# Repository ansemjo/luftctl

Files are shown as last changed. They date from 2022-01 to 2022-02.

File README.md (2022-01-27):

# luftctl

Small ESP32-C3 controller board to power two 12V PWM fans from a single USB plug.

## hardware

Schematic and PCB design can be found in [`hardware/`](hardware/). It is a KiCAD 6 project.

The schematic is available as [a PDF](schematic.pdf).

## firmware

The first simple test just loops through {`5V/off`, `5V/on`, `12V/off`, `12V/on`} with every button press.

Download MicroPython from [micropython.org/download/esp32c3-usb/](https://micropython.org/download/esp32c3-usb/) and flash it with:

```
esptool.py --chip esp32c3 --port /dev/ttyACM0 erase_flash
esptool.py --chip esp32c3 --port /dev/ttyACM0 --baud 460800 write_flash -z 0x0 esp32c3-*.bin
```

Then install a virtualenv with `adafruit-ampy` and upload the [`main.py`](main.py):

```
ampy -p /dev/ttyACM0 put main.py
ampy -p /dev/ttyACM0 reset --hard
```

The red LED will blink upon every state change.

## images

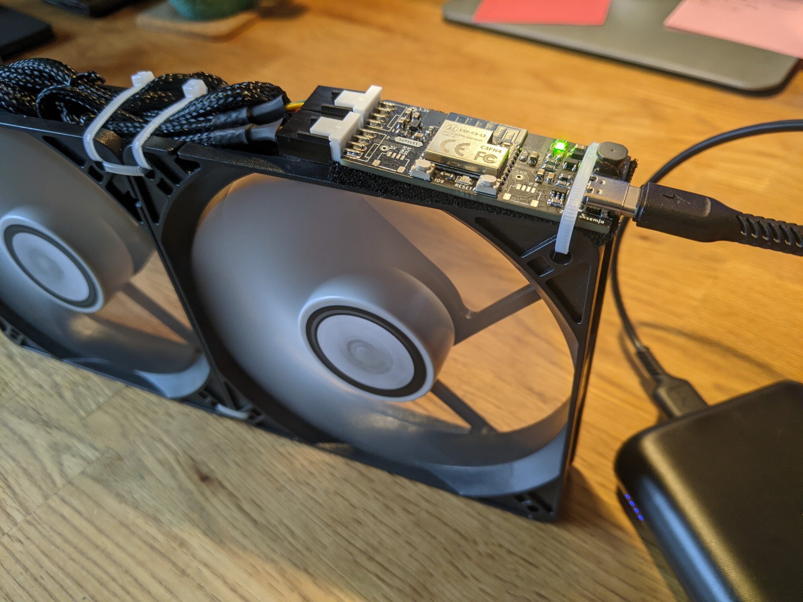
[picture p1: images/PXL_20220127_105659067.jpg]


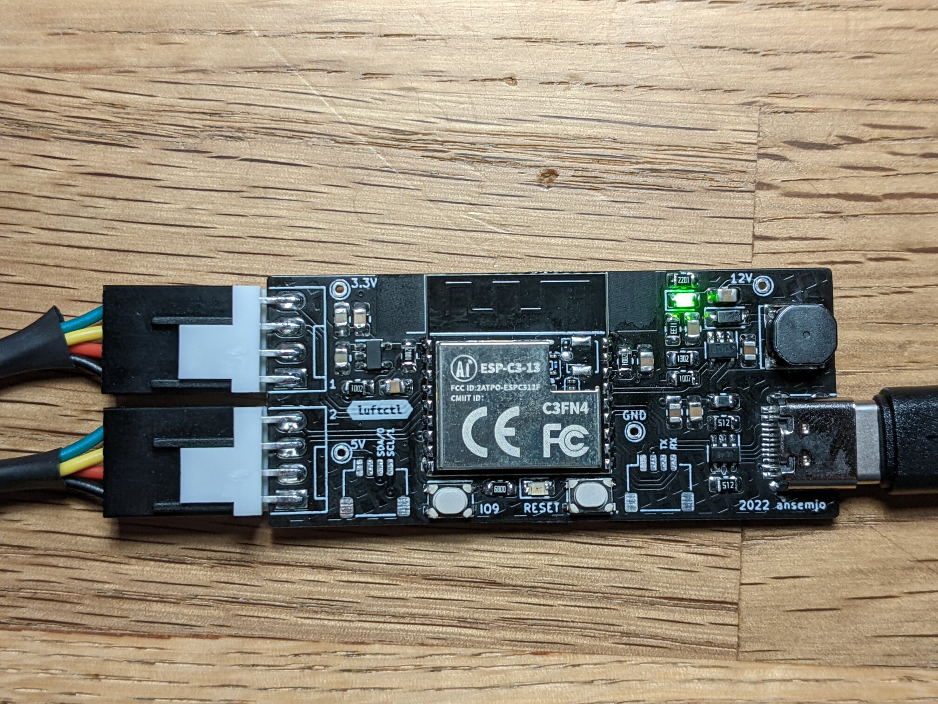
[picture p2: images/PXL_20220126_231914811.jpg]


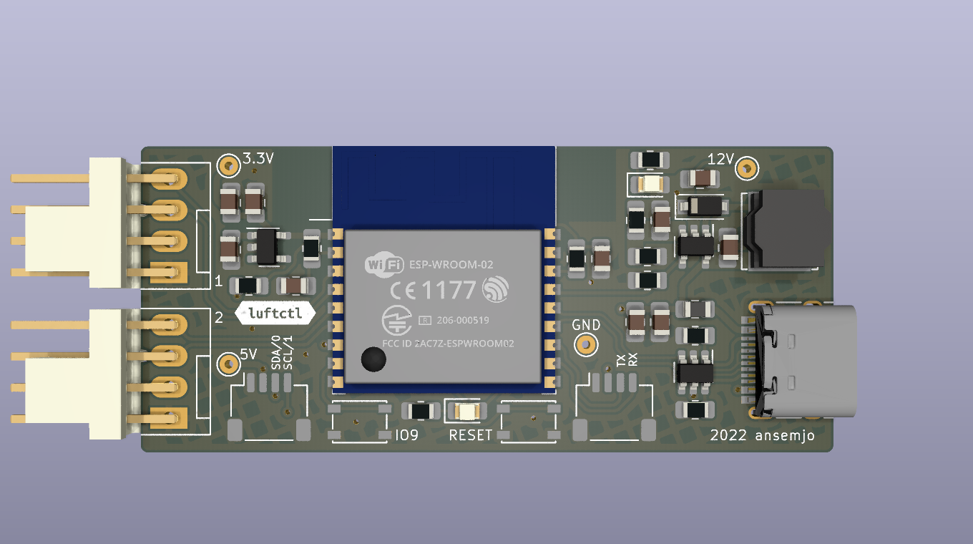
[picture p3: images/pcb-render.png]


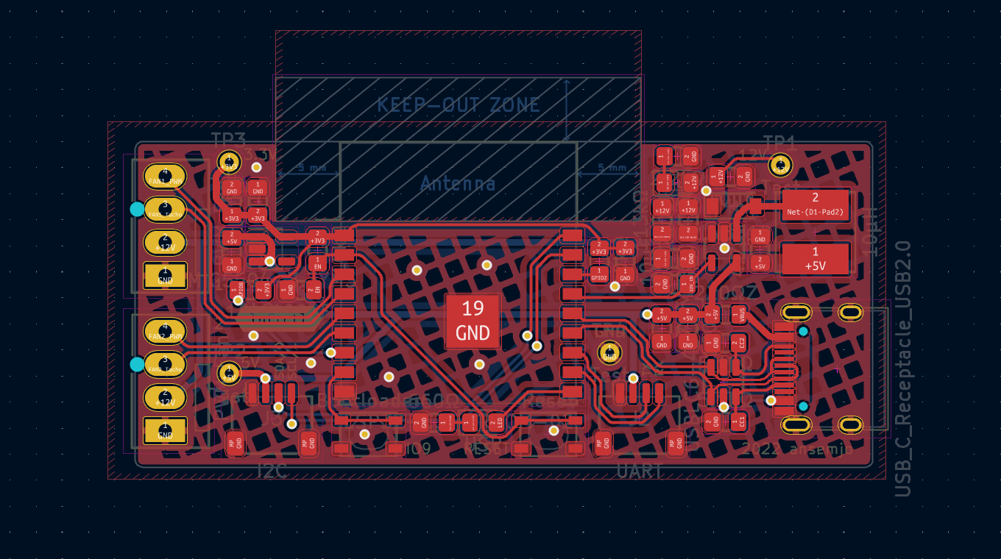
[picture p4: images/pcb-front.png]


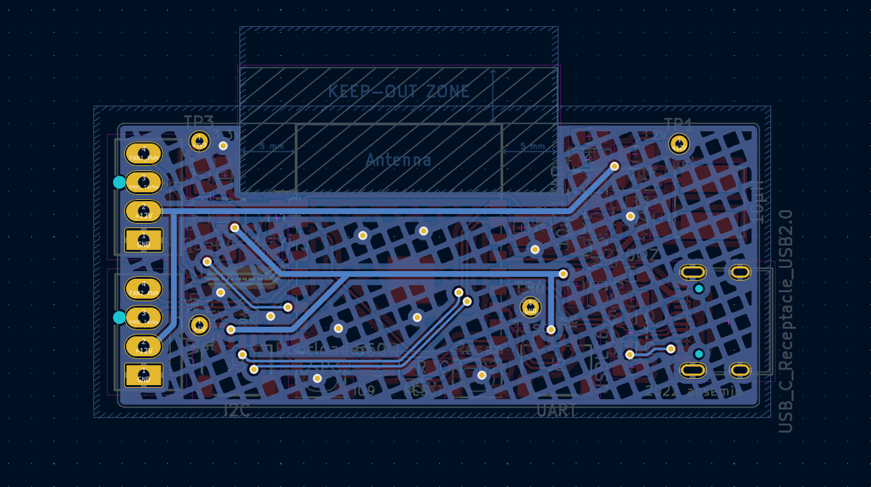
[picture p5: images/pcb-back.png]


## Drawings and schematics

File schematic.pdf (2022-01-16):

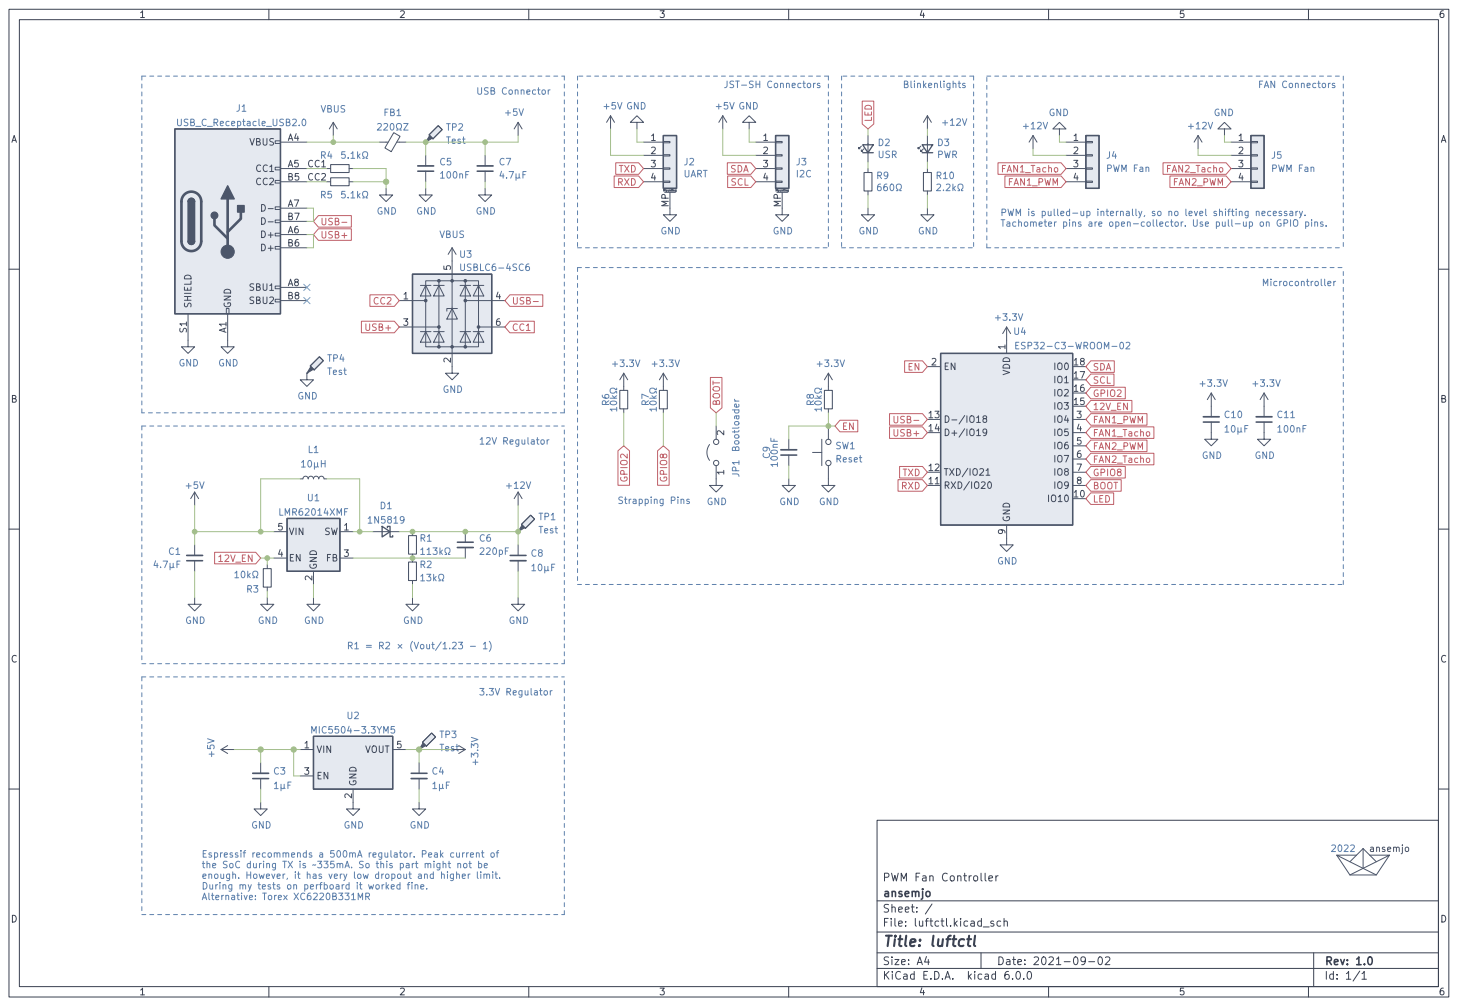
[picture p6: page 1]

Tachometer pins are open-collector. Use pull-up on GPIO pins. USB Connector 12V Regulator

Espressif recommends a 500mA regulator. Peak current of
the SoC during TX is ~335mA. So this part might not be
enough. However, it has very low dropout and higher limit.
During my tests on perfboard it worked fine. Alternative: Torex XC6220B331MR

File: luftctl.kicad_sch Sheet: / ansemjo PWM Fan Controller

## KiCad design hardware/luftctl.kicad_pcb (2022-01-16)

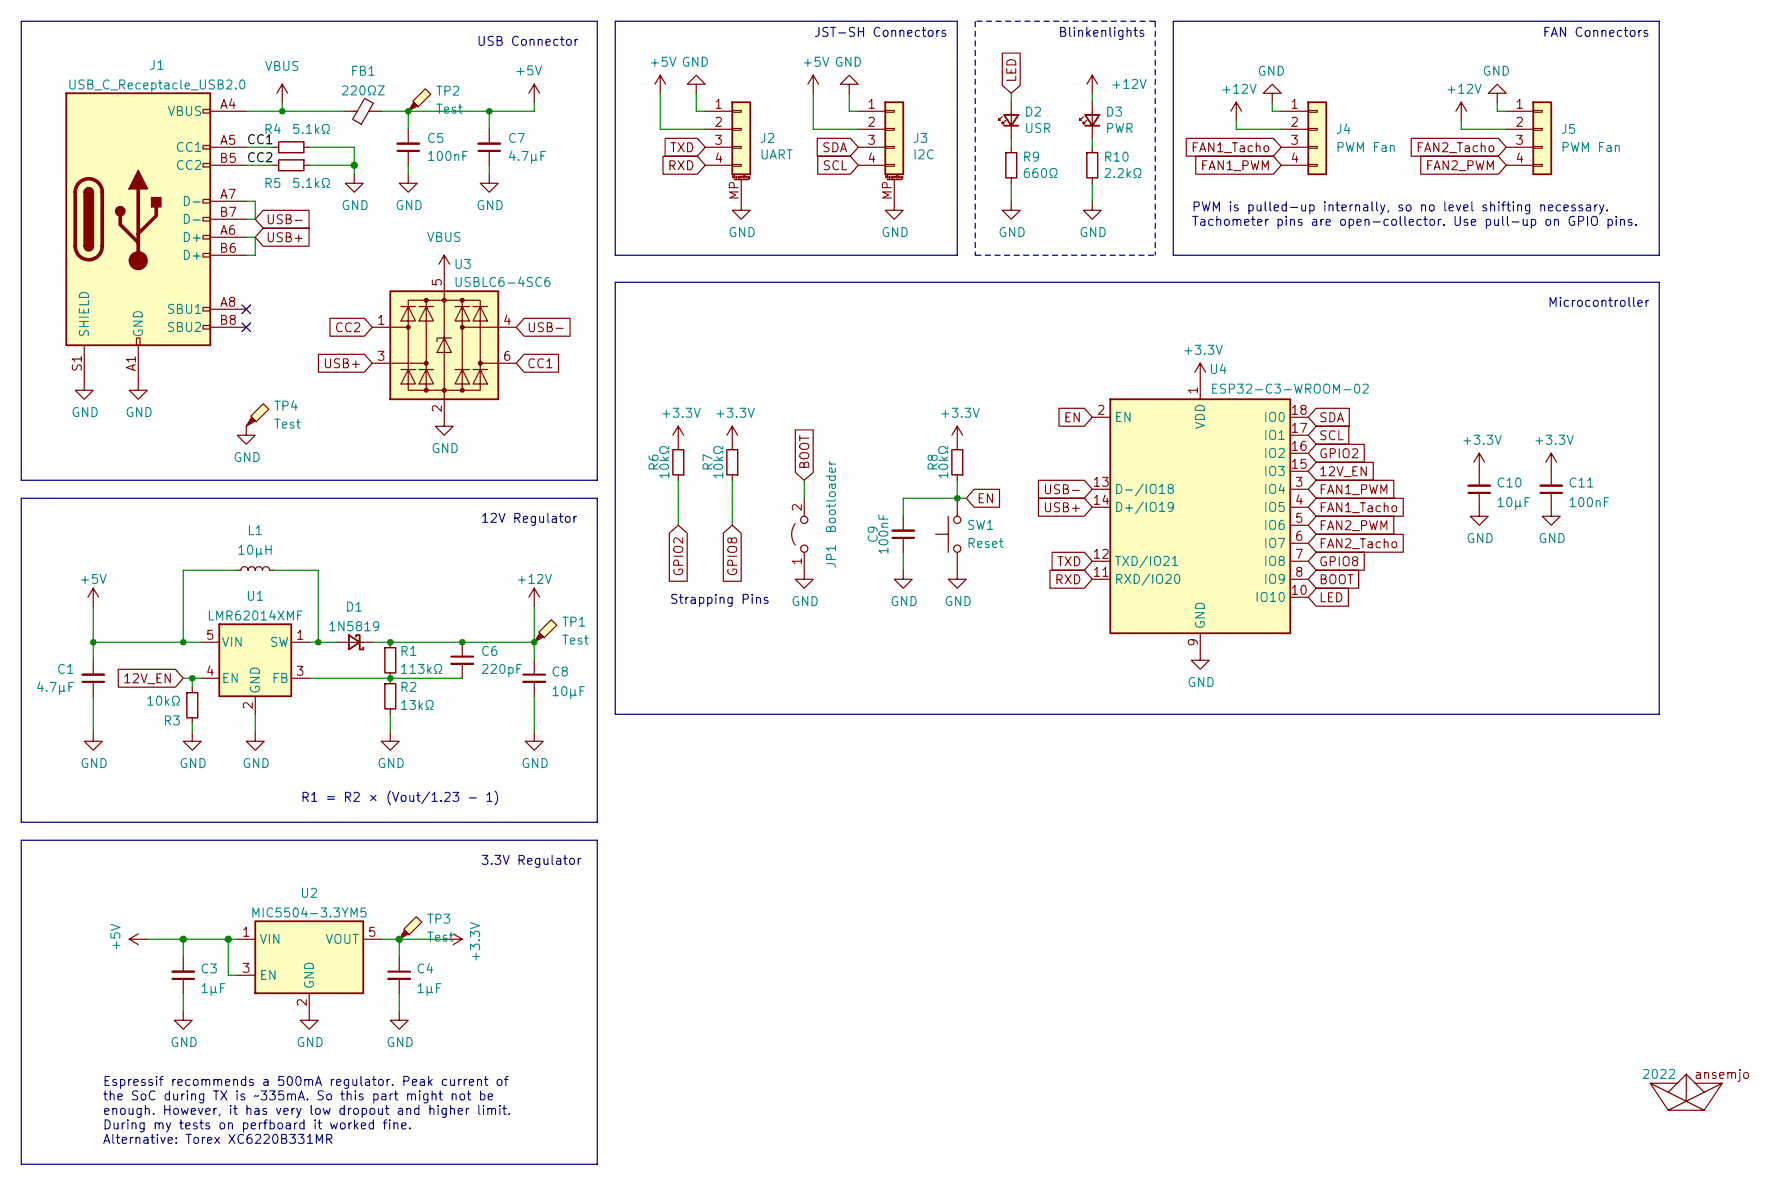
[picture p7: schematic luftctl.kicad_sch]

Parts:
A1: 2022; ahoi
C1, C7: 4.7µF; C_0805_2012Metric_Pad1.18x1.45mm_HandSolder
C3, C4: 1µF; C_0805_2012Metric_Pad1.18x1.45mm_HandSolder
C5, C9, C11: 100nF; C_0805_2012Metric_Pad1.18x1.45mm_HandSolder
C6: 220pF; C_0805_2012Metric_Pad1.18x1.45mm_HandSolder
C8, C10: 10µF; C_0805_2012Metric_Pad1.18x1.45mm_HandSolder
D1: 1N5819; D_SOD-123
D2: USR; LED_0805_2012Metric_Pad1.15x1.40mm_HandSolder
D3: PWR; LED_0805_2012Metric_Pad1.15x1.40mm_HandSolder
FB1: 220ΩZ; L_0805_2012Metric_Pad1.15x1.40mm_HandSolder
J1: USB_C_Receptacle_USB2.0; USB_C_Receptacle_HRO_TYPE-C-31-M-12
J2: UART; JST_SH_SM04B-SRSS-TB_1x04-1MP_P1.00mm_Horizontal
J3: I2C; JST_SH_SM04B-SRSS-TB_1x04-1MP_P1.00mm_Horizontal
J4, J5: PWM Fan; FanPinHeader_1x04_P2.54mm_Vertical
JP1: Bootloader; SW_SPST_PTS810
L1: 10µH; L_Bourns_SRN6045TA
R1: 113kΩ; R_0805_2012Metric_Pad1.20x1.40mm_HandSolder
R2: 13kΩ; R_0805_2012Metric_Pad1.20x1.40mm_HandSolder
R3, R6, R7, R8: 10kΩ; R_0805_2012Metric_Pad1.20x1.40mm_HandSolder
R4, R5: 5.1kΩ; R_0805_2012Metric_Pad1.20x1.40mm_HandSolder
R9: 660Ω; R_0805_2012Metric_Pad1.20x1.40mm_HandSolder
R10: 2.2kΩ; R_0805_2012Metric_Pad1.20x1.40mm_HandSolder
SW1: Reset; SW_SPST_PTS810
TP1, TP2, TP3, TP4: Test; TestPoint_THTPad_D1.5mm_Drill0.7mm
U1: LMR62014XMF; SOT-23-5
U2: MIC5504-3.3YM5; SOT-23-5
U3: USBLC6-4SC6; SOT-23-6; MPN USBLC6-4SC6; Digi-Key_PN 497-4492-1-ND
U4: ESP32-C3-WROOM-02; ESP-WROOM-02

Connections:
12V_EN: R3.1, U1.4 (EN), U4.15 (IO3)
+3V3: C4.1, C10.2, C11.2, R6.2, R7.2, R8.2, TP3.1, U2.5 (VOUT), U4.1 (VDD)
+5V: C1.2, C3.2, C5.2, C7.2, FB1.2, J2.2, J3.2, L1.1, TP2.1, U1.5 (VIN), U2.1 (VIN), U2.3 (EN)
+12V: C6.1, C8.1, D1.1 (K), D3.2 (A), J4.2, J5.2, R1.1, TP1.1
BOOT: JP1.2 (B), U4.8 (IO9)
CC1: J1.A5 (CC1), R4.1, U3.6 (I/O4)
CC2: J1.B5 (CC2), R5.2, U3.1 (I/O1)
EN: C9.2, R8.1, SW1.2, U4.2 (EN)
FAN1_PWM: J4.4, U4.3 (IO4)
FAN1_Tacho: J4.3, U4.4 (IO5)
FAN2_PWM: J5.4, U4.5 (IO6)
FAN2_Tacho: J5.3, U4.6 (IO7)
GND: C1.1, C3.1, C4.2, C5.1, C7.1, C8.2, C9.1, C10.1, C11.1, J1.A1 (GND), J1.A12 (GND), J1.B1 (GND), J1.B12 (GND), J1.S1 (SHIELD), J2.1, J2.MP (MountPin), J3.1, J3.MP (MountPin), J4.1, J5.1, JP1.1 (A), R2.2, R3.2, R4.2, R5.1, R9.2, R10.2, SW1.1, TP4.1, U1.2 (GND), U2.2 (GND), U3.2 (GND), U4.9 (GND), U4.19 (GND)
GPIO2: R6.1, U4.16 (IO2)
GPIO8: R7.1, U4.7 (IO8)
LED: D2.2 (A), U4.10 (IO10)
unnamed: C6.2, R1.2, R2.1, U1.3 (FB)
unnamed: D1.2 (A), L1.2, U1.1 (SW)
unnamed: D2.1 (K), R9.1
unnamed: D3.1 (K), R10.1
RXD: J2.4, U4.11 (RXD/IO20)
SCL: J3.4, U4.17 (IO1)
SDA: J3.3, U4.18 (IO0)
TXD: J2.3, U4.12 (TXD/IO21)
USB+: J1.A6 (D+), J1.B6 (D+), U3.3 (I/O2), U4.14 (D+/IO19)
USB-: J1.A7 (D-), J1.B7 (D-), U3.4 (I/O3), U4.13 (D-/IO18)
VBUS: FB1.1, J1.A4 (VBUS), J1.A9 (VBUS), J1.B4 (VBUS), J1.B9 (VBUS), U3.5 (VBUS)

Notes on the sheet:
3.3V Regulator
PWM is pulled-up internally, so no level shifting necessary. Tachometer pins are open-collector. Use pull-up on GPIO pins.
12V Regulator
Strapping Pins
USB Connector
JST-SH Connectors
Microcontroller
FAN Connectors
R1 = R2 × (Vout/1.23 - 1)
Blinkenlights
Espressif recommends a 500mA regulator. Peak current of the SoC during TX is ~335mA. So this part might not be enough. However, it has very low dropout and higher limit. During my tests on perfboard it worked fine. Alternative: Torex XC6220B331MR

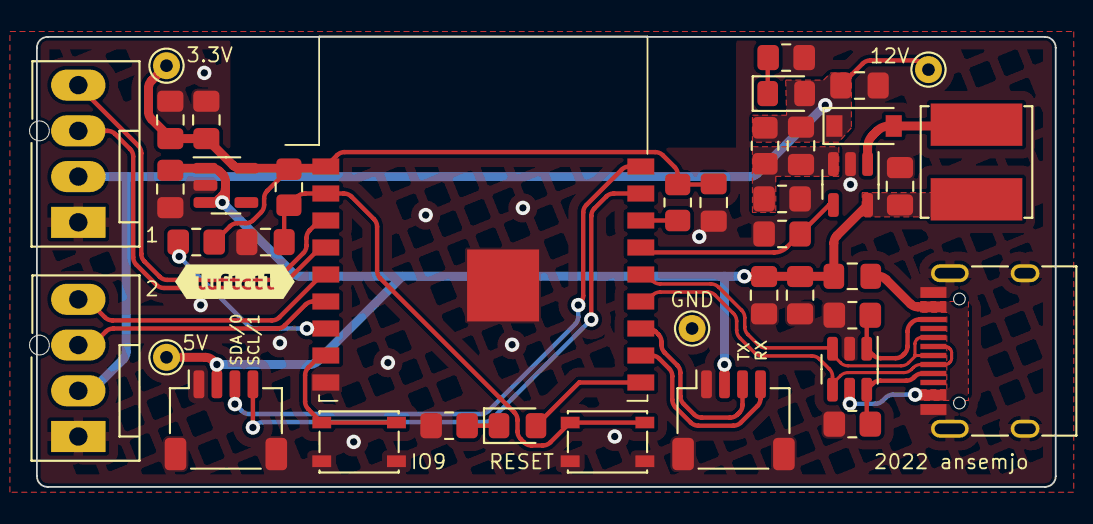
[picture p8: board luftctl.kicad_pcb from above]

Board: 2 copper layers, 56.6 x 25.0 mm, 41 parts (0 on the bottom side), 27 nets.

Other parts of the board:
kibuzzard-61E47F36: G***; kibuzzard-61E47F36

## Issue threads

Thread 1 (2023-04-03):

The 12V LED keep on even Boost_EN low

kscccc, 2023-04-03:
The 12V LED keep on even Boost_EN low.
It should be better by using Boost_EN pin drive the LED.
or
Add a PMOS/Load switch on 5V before Boost IC Vin  to totally cut off the supply.

ansemjo, 2023-04-04:
Well, yes, you're absolutely right. :P
For some reason I thought that disabling the regulator would turn off the 12V supply altogether – which is, of course, not the case due to the straight path through the inductance and diode.

I am currently in no real need for a new luftctl PCB .. do you want to make one with the above already fixed?

I'm thinking that having the "choice" between 5V and 12V is a "feature". But I know that some fans do not completely turn off, even at 5V and zero duty cycle .. so yes, an additional load switch seems like a good idea.

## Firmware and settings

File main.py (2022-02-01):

# example code for ansemjo/luftctl
# 1. flash micropython from https://micropython.org/download/esp32c3-usb/
# 2. upload with `ampy -p /dev/ttyACM0 put main.py`

from machine import Pin as pin, PWM as pwm
from time import sleep, ticks_ms as ticks, ticks_diff as diff

# 12v enable
en = pin(3, pin.OUT, pin.PULL_DOWN)
en.off()

# fan pwms
pwmfreq = 25000
f1 = pwm(pin(4, pin.OUT, pin.PULL_DOWN), pwmfreq)
f2 = pwm(pin(6, pin.OUT, pin.PULL_DOWN), pwmfreq)
f1.duty(0)
f2.duty(0)

# button
btn = pin(9, pin.IN, pin.PULL_UP)

# usr led
led = pwm(pin(10, pin.OUT, pin.PULL_DOWN), 10000)
led.duty(0)
def blink():
  led.duty(1023)
  sleep(0.06)
  led.duty(0)
  sleep(0.04)


# states to cycle through
states = [
  #  label   en  fan1   fan2  led
  (  "off",  0,  0.00,  0.00,    0 ),
  (  "20%",  1,  0.20,  0.20,  100 ),
  (  "45%",  1,  0.45,  0.45,  300 ),
  (  "65%",  1,  0.65,  0.65,  400 ),
  ( "100%",  1,  1.00,  1.00,  800 ),
]

# button callback for state change
i = 0
now = ticks()
def nextstate(_):
  global i, now
  if diff(ticks(), now) < 300:
    print("debounce")
    return
  now = ticks()
  i = (i+1) % len(states)
  txt, e, d1, d2, l = states[i]
  print(f"[{i+1}/{len(states)}] {txt} {l}")
  f1.duty(int(d1*1023))
  f2.duty(int(d2*1023))
  en.value(e)
  blink()
  led.duty(l)

# register callback on falling edge / button press
btn.irq(trigger=pin.IRQ_FALLING, handler=nextstate)

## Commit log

2021-09-02 start project by copying my previous rackluefter schematic
    [luftctl.kicad_sch]
2022-01-16 redesigned schematic for esp32-c3 module, dummy pcb
    [luftctl.kicad_pcb, luftctl.kicad_sch]
2022-01-16 finished pcb layout
    [luftctl.kicad_pcb, luftctl.kicad_sch]
2022-01-16 update readme with new renders and schematic
2022-01-16 add kikit panelization config
    [luftctl.kicad_pcb]
2022-01-16 add gerbers sent to jlcpcb for fab
2022-01-16 add ibom for soldering later
2022-01-26 update with sample µpy code and photo
2022-01-26 add schematic link in readme
2022-01-27 update sample code to handle button presses
2022-01-27 one more photo of assembly with two fans
2022-02-01 improve main.py with pwm for fans and led
